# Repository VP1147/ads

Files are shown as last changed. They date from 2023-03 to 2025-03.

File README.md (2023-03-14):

## Arduino microcontroler code for ADS (Atmospheric Deposition Sampler).

Instructions, circuits and documentation are avaliable on https://github.com/vp1147/ads.  

### Copyright and License

This code is under MIT License (See LICENSE for more information).  

Copyright (c) 2022 *Vinícius Pavão*  

LCA (Atmospheric Sciences Laboratory),
INFI (Institute of Physics),
UFMS (Federal University of Mato Grosso do Sul).

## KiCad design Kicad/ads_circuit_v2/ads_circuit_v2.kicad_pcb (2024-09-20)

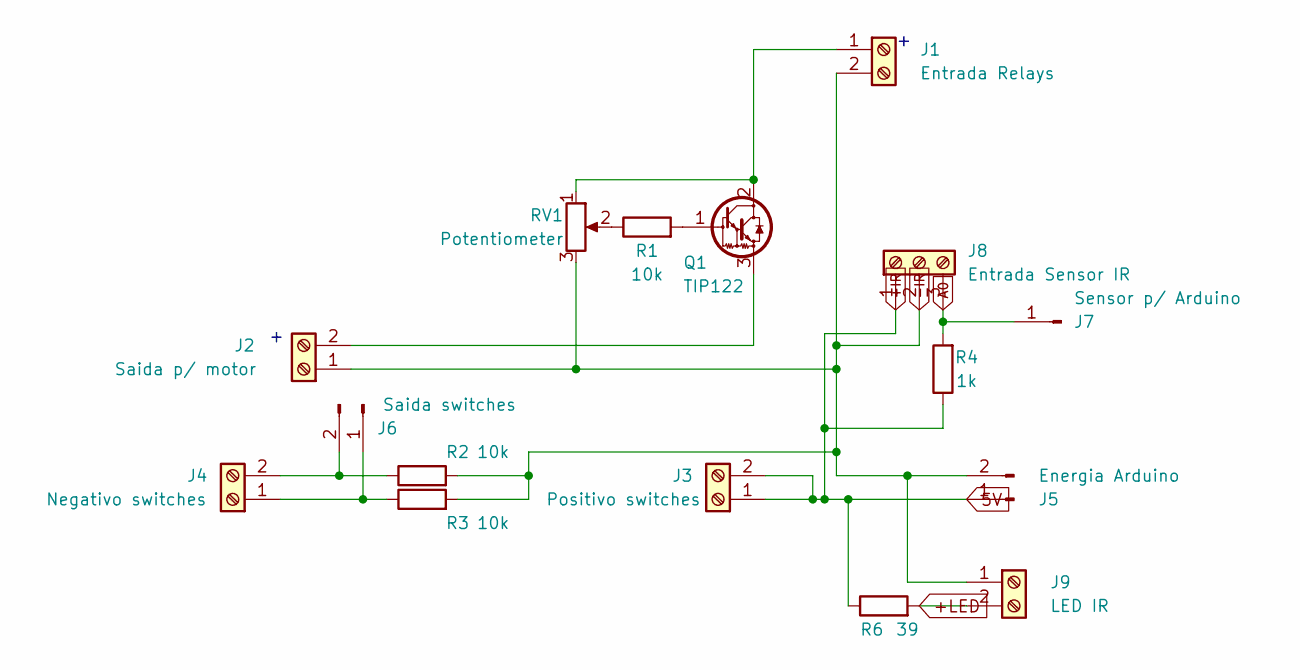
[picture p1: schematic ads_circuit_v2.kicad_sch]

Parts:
J1: Entrada Relays; TerminalBlock_RND_205-00001_1x02_P5.00mm_Horizontal
J2: Saida p/ motor; TerminalBlock_RND_205-00001_1x02_P5.00mm_Horizontal
J3: Positivo switches; TerminalBlock_RND_205-00001_1x02_P5.00mm_Horizontal
J4: Negativo switches; TerminalBlock_RND_205-00001_1x02_P5.00mm_Horizontal
J5: Energia Arduino; PinHeader_1x02_P1.27mm_Vertical
J6: Saida switches; PinHeader_1x02_P1.27mm_Vertical
J7: Sensor p/ Arduino; PinHeader_1x01_P1.27mm_Vertical
J8: Entrada Sensor IR; TerminalBlock_RND_205-00002_1x03_P5.00mm_Horizontal
J9: LED IR; TerminalBlock_RND_205-00001_1x02_P5.00mm_Horizontal
Q1: TIP122; TO-220-3_Vertical
R1, R2, R3: 10k; R_Axial_DIN0207_L6.3mm_D2.5mm_P10.16mm_Horizontal
R4: 1k; R_Axial_DIN0207_L6.3mm_D2.5mm_P10.16mm_Horizontal
R6: 39; R_Axial_DIN0207_L6.3mm_D2.5mm_P10.16mm_Horizontal
RV1: Potentiometer; Potentiometer_Alps_RK163_Single_Horizontal

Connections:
5V: J3.1, J3.2, J5.1, J8.1, R4.1, R6.1
+LED: J9.2, R6.2
-IR: J1.2, J2.1, J5.2, J8.2, J9.1, R2.2, R3.2, RV1.3
A0: J7.1, J8.3, R4.2
unnamed: J1.1, Q1.2 (C), RV1.1
unnamed: J2.2, Q1.3 (E)
unnamed: J4.1, J6.1, R3.1
unnamed: J4.2, J6.2, R2.1
unnamed: Q1.1 (B), R1.2
unnamed: R1.1, RV1.2

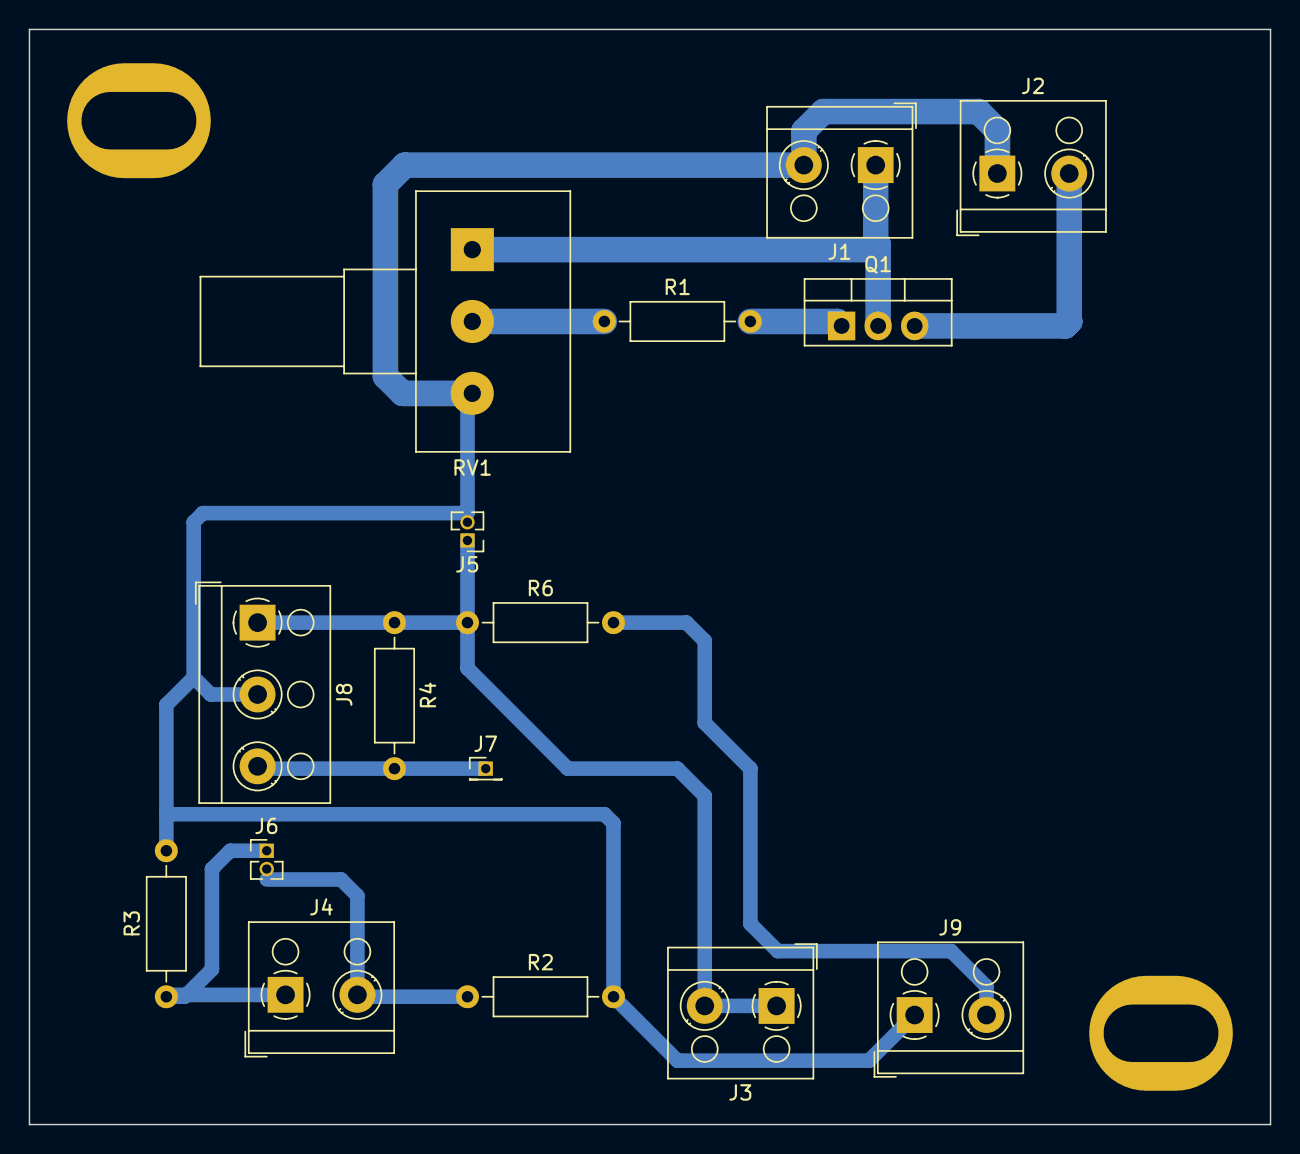
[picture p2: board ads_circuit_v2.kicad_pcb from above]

Board: 2 copper layers, 86.4 x 76.2 mm, 16 parts (0 on the bottom side), 10 nets.

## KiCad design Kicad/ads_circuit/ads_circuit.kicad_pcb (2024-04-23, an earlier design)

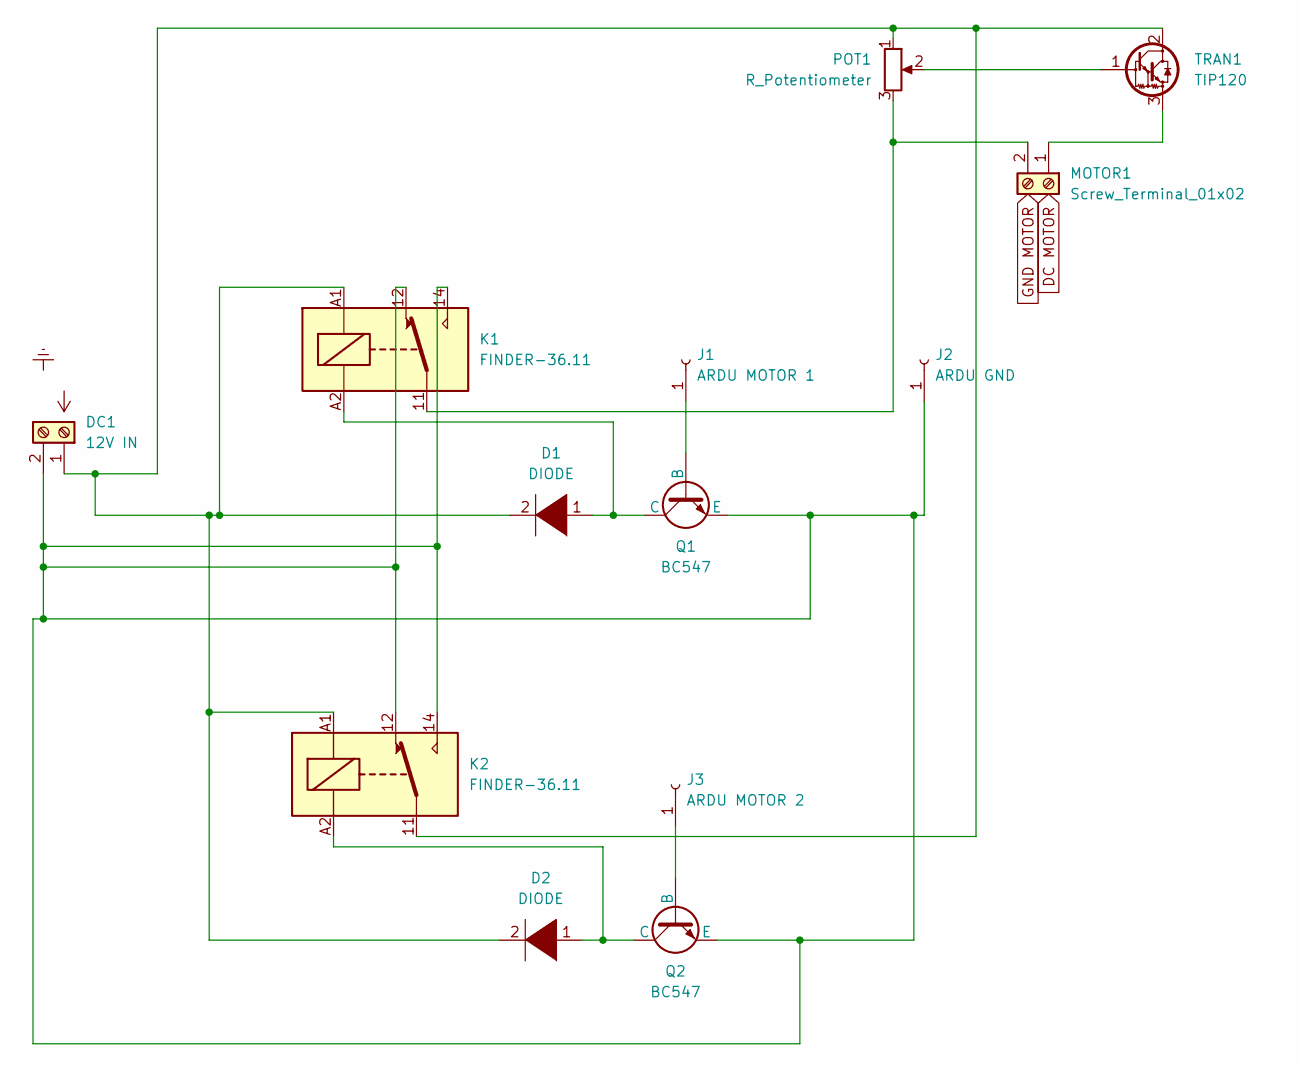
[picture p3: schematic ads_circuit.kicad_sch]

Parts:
D1, D2: DIODE; D_A-405_P7.62mm_Horizontal
DC1: 12V IN; TerminalBlock_RND_205-00001_1x02_P5.00mm_Horizontal
J1: ARDU MOTOR 1; PinHeader_1x01_P1.00mm_Vertical
J2: ARDU GND; PinHeader_1x01_P1.00mm_Vertical
J3: ARDU MOTOR 2; PinHeader_1x01_P1.00mm_Vertical
K1, K2: FINDER-36.11; Relay_SPDT_Finder_36.11
MOTOR1: Screw_Terminal_01x02; TerminalBlock_RND_205-00001_1x02_P5.00mm_Horizontal
POT1: R_Potentiometer; Potentiometer_Piher_T-16H_Single_Horizontal
Q1, Q2: BC547; TO-92_Inline
TRAN1: TIP120; TO-220-3_Vertical

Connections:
unnamed: D1.1 (K), K1.A2, Q1.1 (C)
unnamed: D1.2 (A), D2.2 (A), DC1.1, K1.A1, K2.11, K2.A1, POT1.1, TRAN1.2 (C)
unnamed: D2.1 (K), K2.A2, Q2.1 (C)
unnamed: DC1.2, J2.1, K1.12, K1.14, K2.12, K2.14, Q1.3 (E), Q2.3 (E)
unnamed: J1.1, Q1.2 (B)
unnamed: J3.1, Q2.2 (B)
unnamed: K1.11, MOTOR1.2, POT1.3
unnamed: MOTOR1.1, TRAN1.3 (E)
unnamed: POT1.2, TRAN1.1 (B)

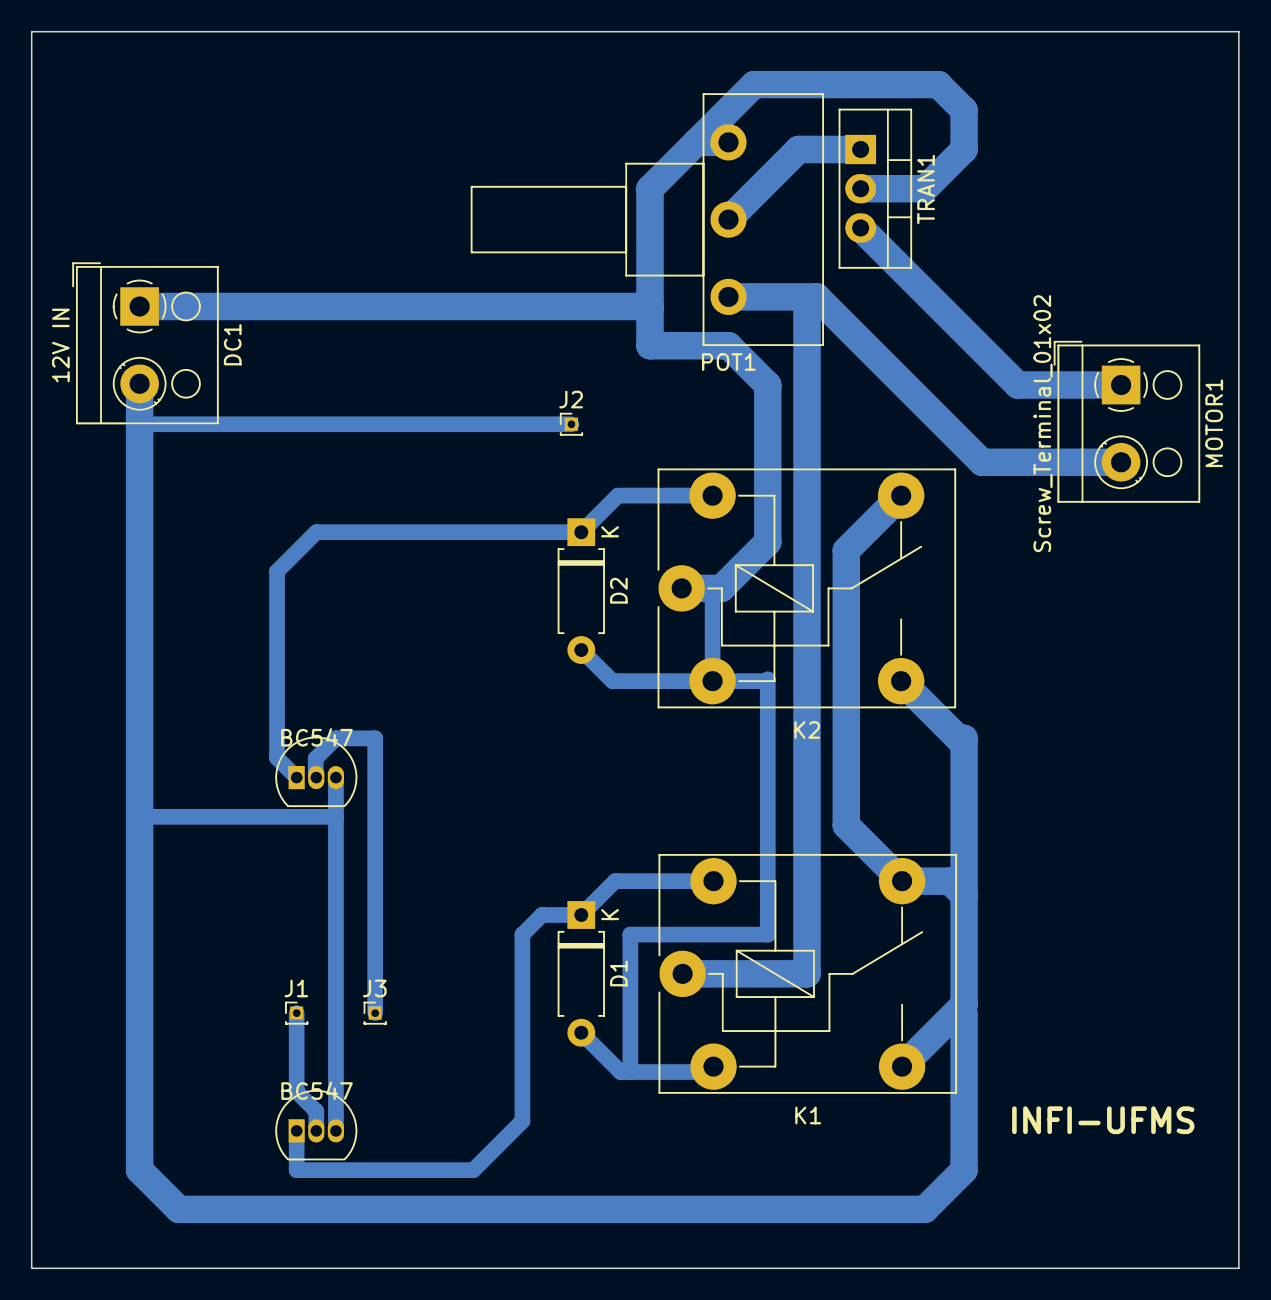
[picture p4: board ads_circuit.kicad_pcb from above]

Board: 2 copper layers, 78.1 x 80.0 mm, 13 parts (0 on the bottom side), 9 nets.

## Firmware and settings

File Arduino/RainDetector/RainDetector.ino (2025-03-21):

/*
  "Rain Detector"
  Arduino microcontroler code for ADS -
  Atmospheric Deposition Sampler).
  Instructions, circuits and documentation are
  avaliable on https://github.com/vp1147/ads.

  MIT License (See LICENSE for more information)
  Copyright (c) 2022 Vinícius Pavão

  LCA (Atmospheric Sciences Laboratory)
  INFI (Institute of Physics)
  UFMS (Federal University of Mato Grosso do Sul)
*/

// Enviromment variables
#define NONSTOP         false                // Motor Always on (only for debug-adjustemment).
                                             // May cause overheating!
#define SERIALRETURN    true                // Send verbose variable data to serial (debug or adjustemment).

#define IGNOREMS        false

// Defining I/O pins
int Sensor = A0;                             // Infrared Sensor (input)
int nmotor = 5;                              // Close signal pin (output)
int pmotor = 6;                              // Open signal pin (output)

// Microswitch pins - Detects if the lid is fully open or fully closed before stopping the motor
int ms_fullopen = 8;      // Open switch (input)
int ms_fullclose = 9;     // Closed switch (input)
int open_button = 7;

// Information LEDs
int halt_led = 7; // RED
int op_cl_led = 10; // YELLOW
int det_led = 11; // GREEN

// Declaring global variables
const long interval = 10000;
unsigned long previousMillis = 0;
long int meter;
bool IsClosed = true; // Cycle starts closed
int counter = 0;
int timer = 0;
int lim = 200;        // Threshold value for calibration (adjustable)
int bg;               // Adjusted by calibrate() function
String input;         // Stores serial input text

// Defining sensor parameters
int ceiling = 600 ;           // Max. value for sensor counter - higher means
                              // slower response to rain <stopping>
int activate = 60 ;          // Value in which the opening signal is sent - higher
                              // means slower response to rain <starting>

void setup() {
  // Serial -> Input/Output  
  Serial.begin(9600);
  Serial.println(">> Starting");

  // Setting motor pins
  pinMode(pmotor, OUTPUT); pinMode(nmotor, OUTPUT);

  // Send HH to Relay - motor poweroff
  digitalWrite(pmotor, HIGH); digitalWrite(nmotor, HIGH);

  // Setting sensor pin
  pinMode(Sensor, INPUT);

  pinMode(nmotor, OUTPUT);
  pinMode(pmotor, OUTPUT);

  pinMode(halt_led, OUTPUT);
  pinMode(op_cl_led, OUTPUT);
  pinMode(det_led, OUTPUT);

  pinMode(ms_fullopen, INPUT);
  pinMode(ms_fullclose, INPUT);
  
  if(VerifyState() == 'o') { close(true); }
  else if(VerifyState() == 'e') { close(false); }
}

void loop() {
  if(NONSTOP == true) { digitalWrite(pmotor, LOW); digitalWrite(nmotor, HIGH); }
  else {                      // Normal operation
    digitalWrite(det_led, LOW);
    digitalWrite(20, LOW);
    delay(30);
    if(SERIALRETURN == true) {
      // Output sensor parameters to serial
      Serial.print("\tREAD: "); Serial.print(analogRead(Sensor)); Serial.print("\t\t");
      Serial.print("METER: "); Serial.print(meter); Serial.print("\t\t");
      Serial.print("CLOSE: "); Serial.print(IsClosed); Serial.print("\t\t");
      Serial.print("MS_OPN: "); Serial.print(digitalRead(ms_fullopen)); Serial.print("\t");
      Serial.print("MS_CLS: "); Serial.print(digitalRead(ms_fullclose)); Serial.print("\t");
      Serial.print("BTN: "); Serial.print(digitalRead(open_button)); Serial.print("\t");
      Serial.print("\n");
    }

    // Check if diference between readings exceeds bg + lim
    // Also if the meter value doesnt exceed the wall limiter.
    if(analogRead(Sensor) < 1000 && meter < ceiling) {
      meter += 40;
      digitalWrite(det_led, HIGH);
      digitalWrite(14, HIGH);
    }
    // Starts opening cycle if meter reacher the activation value
    if(meter > 0) { 
      if(meter > activate && IsClosed == true) { open(false); }
      // If open, subtracts from meter value until it reaches zero
      meter-- ;
    }
    // if meter value reaches one, starts closing cycle
    if(meter == 1 && IsClosed == false && digitalRead(open_button) == LOW) { close(false); }


    counter++ ;
    
  // Receive serial commands  
    if(Serial.available()) {
      input = Serial.readStringUntil('\n');
      if(input == "open") { open(true); }
      else if(input == "close") { close(true); }
      else { Serial.println(">> Unknown command: "+input); }
    }

    // Open if external button is pressed
    if(digitalRead(open_button) == HIGH && IsClosed == true) {
      open(true);
    }
  }

  // Measure state from microswitches
  if(VerifyState() == 'o') {
    IsClosed == false;
  }
  else if(VerifyState() == 'c') {
    IsClosed == true;
  }
}

int calibrate(int port, int steps, int period) {   // i.e. calibrate(Sensor, 100, 5000)
  int tot=0;
  for(int i=0; i<steps; i++) {
    tot+=analogRead(port);
    delay(int(period/steps));
  }
  return tot/steps;
}

void open(bool verify_closed) {
  if(VerifyState() == 'c' || verify_closed == false) {
    // Starts the opening cycle
    Serial.println(">> Opening ...");

    // Wait until lid is fully open
    timer = 0;
    while(digitalRead(ms_fullopen) == LOW || timer == 4000) {
      digitalWrite(pmotor, LOW); digitalWrite(nmotor, HIGH);
      delay(1);
      timer++;
    }
    delay(100);
    // Send HH to Relay - motor poweroff
    digitalWrite(pmotor, HIGH); digitalWrite(nmotor, HIGH);
    Serial.println(">> Lid is fully open");
    IsClosed = false;
  }
  else if(VerifyState() == 'o' && verify_closed == true) {
    Serial.println(">> OPENING CYCLE STOPPED - LID IS OPEN");
  }
  else if(VerifyState() == 'e' && verify_closed == true) {
    Serial.println(">> OPENING CYCLE STOPPED - SYSTEM IS HALTED");
  }
}

// Verifies microswitch state
char VerifyState() {
  if(digitalRead(ms_fullclose) == HIGH) {
    return 'c';
  }
  else if(digitalRead(ms_fullopen) == HIGH) {
    return 'o';
  }
  else {
    Serial.println(">> ERROR - COULD NOT DETECT ANY MS SIGNAL!");
    return 'e';
  }
}
void close(bool verify_open) {
  if(VerifyState() == 'o' || verify_open == false) {
    // Starts the closing cycle
    Serial.println(">> Closing ...");
    timer = 0;
    while(digitalRead(ms_fullclose) == LOW || timer == 3000) {
      digitalWrite(nmotor, LOW); digitalWrite(pmotor, HIGH);
      delay(1);
      timer++;
    }
    // Send HH to Relay - motor poweroff
    digitalWrite(pmotor, HIGH); digitalWrite(nmotor, HIGH);
    Serial.println(">> Lid is fully closed");
    IsClosed = true;
  }
  else if(VerifyState() == 'c' || verify_open == true) {
    Serial.println(">> CLOSING CYCLE STOPPED - LID IS CLOSED");
  }
  else if(VerifyState() == 'e' || verify_open == true) {
    Serial.println(">> CLOSING CYCLE STOPPED - SYSTEM IS HALTED");
  }
}

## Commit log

2022-12-12 Updated scheme
    [Scheme.fzz]
2023-01-11 Create TIP120 Hi-Current Darlington Transistor.fzpz
2023-02-04 Motor control and commands
    [Scheme.fzz]
2023-12-06 Update scheme
    [Scheme.fzz, ads_circuit.kicad_pcb, ads_circuit.kicad_sch]
2024-02-02 Update circuit
    [Scheme.fzz, ads_circuit.kicad_pcb, ads_circuit.kicad_sch]
2024-04-23 Kicad scheme
    [ads_circuit.kicad_pcb, ads_circuit.kicad_sch]
2024-09-20 Update KiCAD scheme
    [ads_circuit_v2.kicad_pcb, ads_circuit_v2.kicad_sch]
2024-09-20 Added information LEDs
2025-02-25 Updated Kicad model
